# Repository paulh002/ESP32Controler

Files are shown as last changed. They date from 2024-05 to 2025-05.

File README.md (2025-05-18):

# This repo is archived
Current Arduino version has made this project not fitting anymore in the ESP32 also libraries have updated and are not matching with the code any more.
This repo is only for reference.

# ESP32 USB CAT Controler

A USB remote control for sdrberry or other CAT enabled SDR or VFO
It also for sdrberry controles bandpassfilter and lpf

ToDo:
- add i2c for LPF and BPF

Done:
- USB CAT interface support 

Please add/modify a file credentials.h to the source files for wifi
```
#ifndef _CREDENTIALS_H_			// Prevent double inclusion
#define _CREDENTIALS_H_

#define NUMBR_SSID  2
const char* _ssid[] = {"wifi-ssid1", "wifi-ssid2" };
const char* _password[] = {"password", "password"};

#endif
```

sdrberry

Radioberry demo (https://youtu.be/PQ_Np5SfcxA)

# ESP32 Remote control for raspberry pi
sdrberry

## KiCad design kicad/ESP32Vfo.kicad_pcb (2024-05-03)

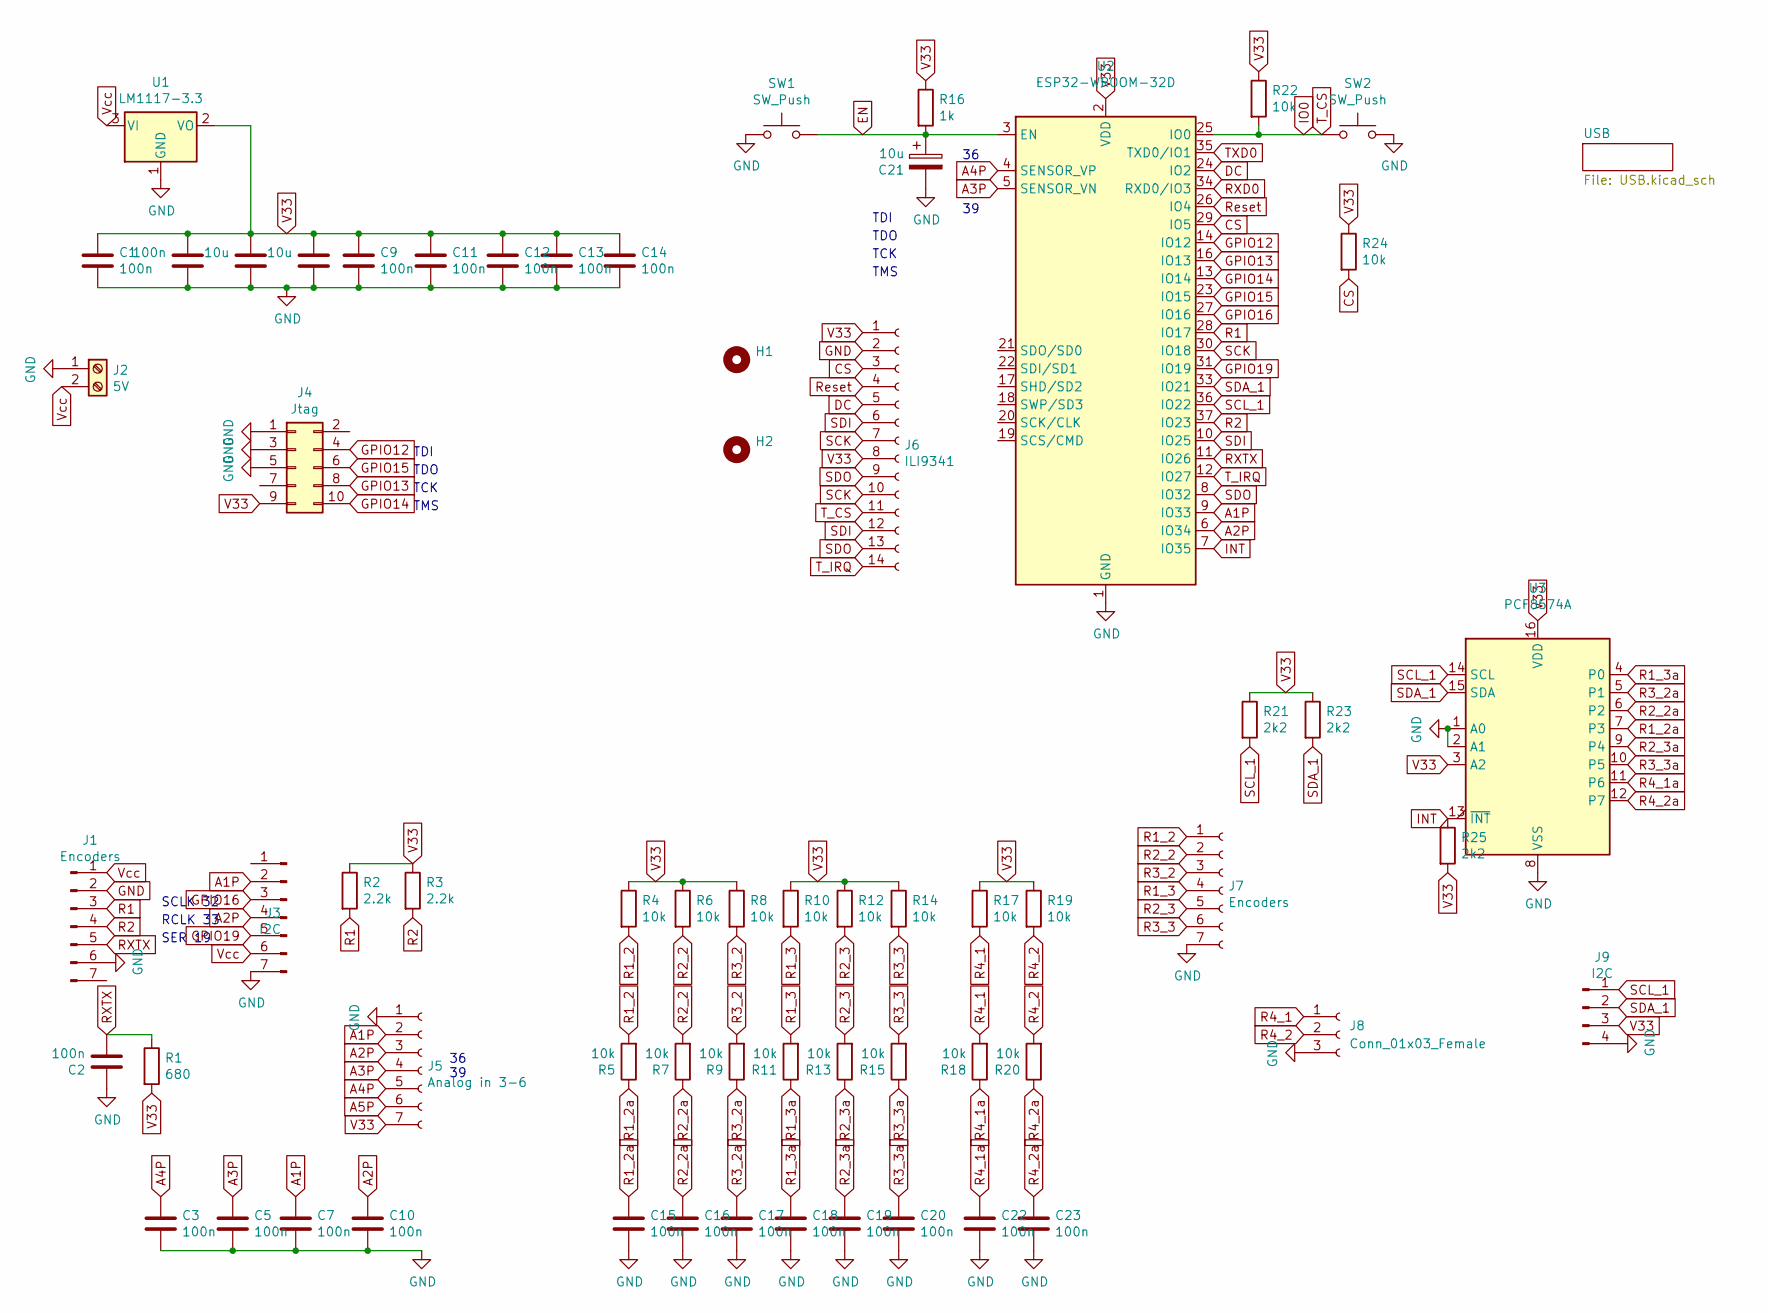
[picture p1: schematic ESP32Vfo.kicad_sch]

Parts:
C1, C2, C3, C4, C5, C7, C9, C10, C11, C12, C13, C14, C15, C16, C17, C18, C19, C20, C22, C23: 100n; C_0805_2012Metric
C6, C21: 10u; C_1206_3216Metric_Pad1.42x1.75mm_HandSolder
C8: 10u; C_0805_2012Metric
H1, H2: MountingHole_3.2mm_M3
J1, J7: Encoders; PinSocket_1x07_P2.54mm_Vertical
J2: 5V; TerminalBlock_MetzConnect_Type011_RT05502HBWC_1x02_P5.00mm_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
J3: I2C; PinSocket_1x07_P2.54mm_Vertical
J4: Jtag; PinSocket_2x05_P2.54mm_Vertical
J5: Analog in 3-6; PinSocket_1x07_P2.54mm_Vertical
J6: ILI9341; PinSocket_1x14_P2.54mm_Vertical
J8: Conn_01x03_Female; PinSocket_1x03_P2.54mm_Vertical
J9: I2C; JST_PH_S4B-PH-SM4-TB_1x04-1MP_P2.00mm_Horizontal
R1: 680; R_0805_2012Metric
R2, R3: 2.2k; R_0805_2012Metric
R4, R5, R6, R7, R8, R9, R10, R11, R12, R13, R14, R15, R17, R18, R19, R20, R22, R24: 10k; R_0805_2012Metric
R16: 1k; R_0805_2012Metric
R21, R23, R25: 2k2; R_0805_2012Metric
SW1, SW2: SW_Push; TS-1088R-02526
U1: LM1117-3.3; SOT-223-3_TabPin2
U2: ESP32-WROOM-32D; ESP32-WROOM-32
U3: PCF8574A; SOP-16_7.5x10.4mm_P1.27mm

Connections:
A1P: C7.2, J3.2, J5.2, U2.9 (IO33)
A2P: C10.2, J3.4, J5.3, U2.6 (IO34)
A3P: C5.2, J5.4, U2.5 (SENSOR_VN)
A4P: C3.2, J5.5, U2.4 (SENSOR_VP)
A5P: J5.6
CS: J6.3, R24.2, U2.29 (IO5)
DC: J6.5, U2.24 (IO2)
EN: C21.1, R16.2, SW1.2, U2.3 (EN); also elsewhere on the board
GND: C1.1, C2.2, C3.1, C4.2, C5.1, C6.2, C7.1, C8.2, C9.1, C10.1, C11.1, C12.1, C13.1, C14.1, C15.1, C16.1, C17.1, C18.1, C19.1, C20.1, C21.2, C22.1, C23.1, J1.2, J1.6, J2.1, J3.7, J4.1, J4.3, J4.5, J5.1, J6.2, J7.7, J8.3, J9.4, SW1.1, SW2.2, U1.1 (GND), U2.1 (GND), U2.15 (GND), U2.38 (GND), U2.39 (GND), U3.1 (A0), U3.2 (A1), U3.8 (VSS); also elsewhere on the board
GPIO12: J4.4, U2.14 (IO12)
GPIO13: J4.8, U2.16 (IO13)
GPIO14: J4.10, U2.13 (IO14)
GPIO15: J4.6, U2.23 (IO15)
GPIO16: J3.3, U2.27 (IO16)
GPIO19: J3.5, U2.31 (IO19)
INT: R25.1, U2.7 (IO35), U3.13 (~INT)
IO0: J6.11, R22.2, SW2.1, U2.25 (IO0); also elsewhere on the board
R1: J1.3, R2.2, U2.28 (IO17)
R1_2: J7.1, R4.2, R5.2
R1_2a: C15.2, R5.1, U3.7 (P3)
R1_3: J7.4, R10.2, R11.2
R1_3a: C18.2, R11.1, U3.4 (P0)
R2: J1.4, R3.2, U2.37 (IO23)
R2_2: J7.2, R6.2, R7.2
R2_2a: C16.2, R7.1, U3.6 (P2)
R2_3: J7.5, R12.2, R13.2
R2_3a: C19.2, R13.1, U3.9 (P4)
R3_2: J7.3, R8.2, R9.2
R3_2a: C17.2, R9.1, U3.5 (P1)
R3_3: J7.6, R14.2, R15.2
R3_3a: C20.2, R15.1, U3.10 (P5)
R4_1: J8.1, R17.2, R18.2
R4_1a: C22.2, R18.1, U3.11 (P6)
R4_2: J8.2, R19.2, R20.2
R4_2a: C23.2, R20.1, U3.12 (P7)
RXD0: U2.34 (RXD0/IO3); also elsewhere on the board
RXTX: C2.1, J1.5, R1.1, U2.11 (IO26)
Reset: J6.4, U2.26 (IO4)
SCK: J6.7, J6.10, U2.30 (IO18)
SCL_1: J9.1, R21.2, U2.36 (IO22), U3.14 (SCL)
SDA_1: J9.2, R23.2, U2.33 (IO21), U3.15 (SDA)
SDI: J6.6, J6.12, U2.10 (IO25)
SDO: J6.9, J6.13, U2.8 (IO32)
TXD0: U2.35 (TXD0/IO1); also elsewhere on the board
T_IRQ: J6.14, U2.12 (IO27)
V33: C1.2, C4.1, C6.1, C8.1, C9.2, C11.2, C12.2, C13.2, C14.2, J4.9, J5.7, J6.1, J6.8, J9.3, R1.2, R2.1, R3.1, R4.1, R6.1, R8.1, R10.1, R12.1, R14.1, R16.1, R17.1, R19.1, R21.1, R22.1, R23.1, R24.1, R25.2, U1.2 (VO), U2.2 (VDD), U3.3 (A2), U3.16 (VDD); also elsewhere on the board
Vcc: J1.1, J2.2, J3.6, U1.3 (VI); also elsewhere on the board

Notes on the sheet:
TDI
TMS
TCK
TDO
SER 19
SCLK 32
RCLK 33
36 39

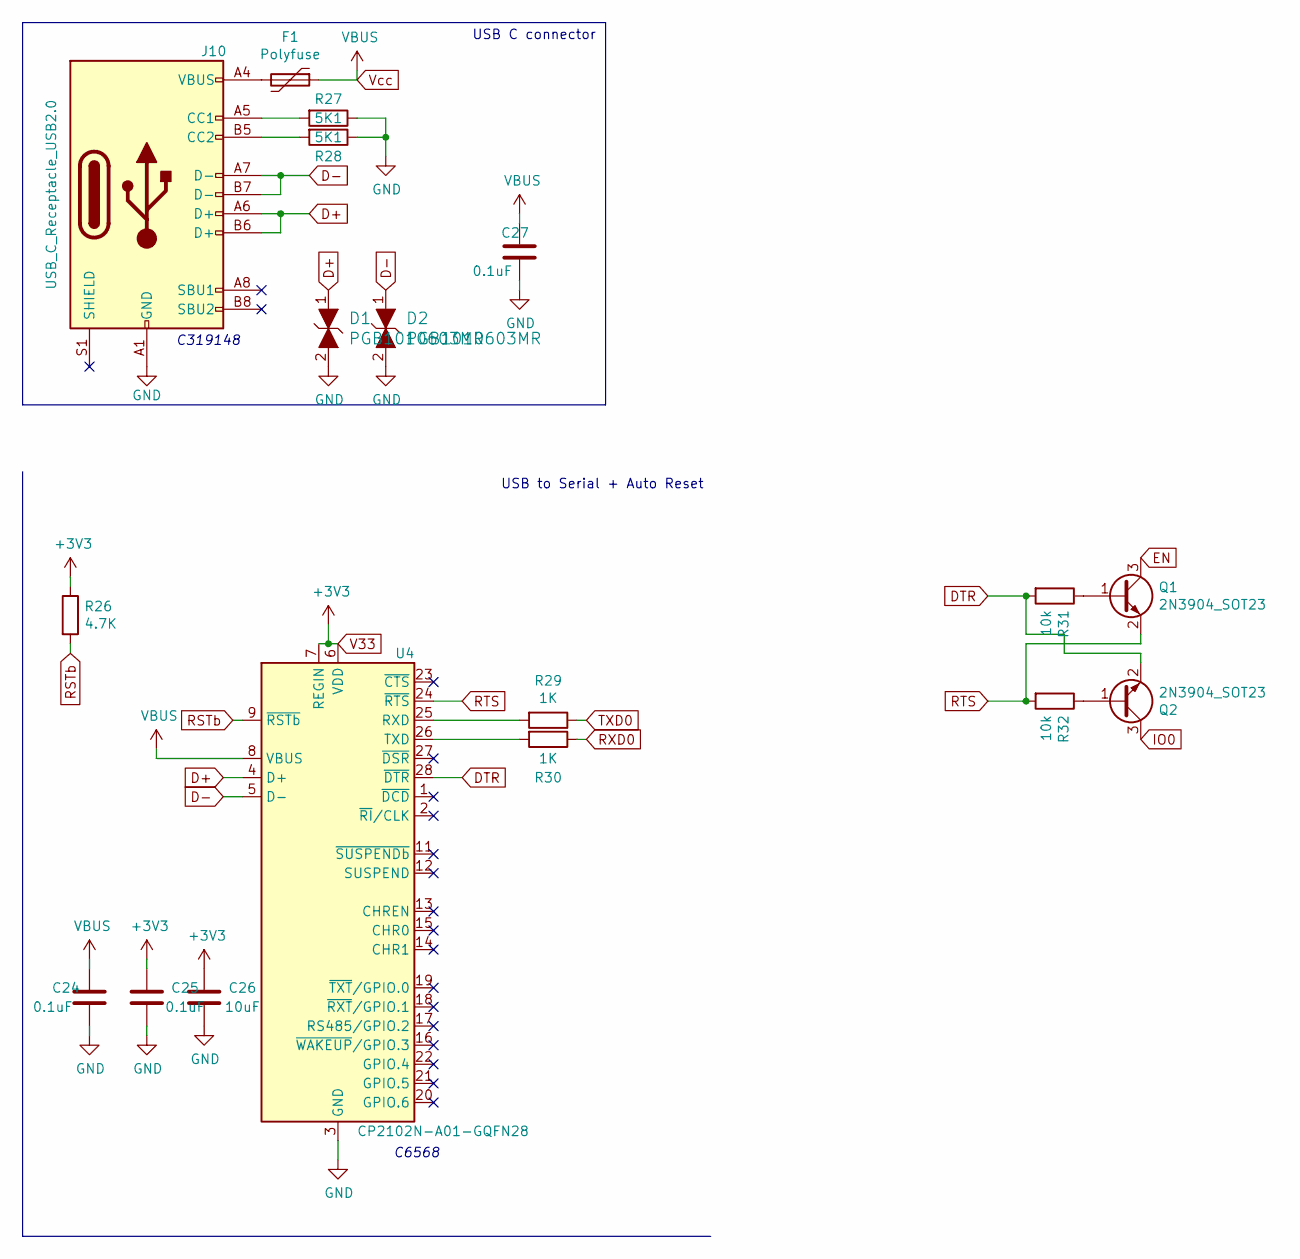
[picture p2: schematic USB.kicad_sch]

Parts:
C24, C25, C27: 0.1uF; C_0805_2012Metric
C26: 10uF; C_0805_2012Metric
D1, D2: PGB1010603MR; 0603; MPN PGB1010603MR; Digi-Key_PN F2594CT-ND
F1: Polyfuse; Fuse_0805_2012Metric
J10: USB_C_Receptacle_USB2.0; USB_C_Receptacle_XKB_U262-16XN-4BVC11
Q1, Q2: 2N3904_SOT23; SOT-23
R26: 4.7K; R_0805_2012Metric
R27, R28: 5K1; R_0805_2012Metric
R29, R30: 1K; R_0805_2012Metric
R31, R32: 10k; R_0805_2012Metric
U4: CP2102N-A01-GQFN28; QFN-28-1EP_5x5mm_P0.5mm_EP3.35x3.35mm

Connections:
D+: D1.1, J10.A6 (D+), J10.B6 (D+), U4.4 (D+)
D-: D2.1, J10.A7 (D-), J10.B7 (D-), U4.5 (D-)
DTR: Q2.2 (E), R31.2, U4.28 (~DTR)
EN: Q1.3 (C); also elsewhere on the board
GND: C24.2, C25.2, C26.2, C27.2, D1.2, D2.2, J10.A1 (GND), J10.A12 (GND), J10.B1 (GND), J10.B12 (GND), R27.1, R28.1, U4.3 (GND), U4.29 (GND); also elsewhere on the board
IO0: Q2.3 (C); also elsewhere on the board
unnamed: F1.2, J10.A4 (VBUS), J10.A9 (VBUS), J10.B4 (VBUS), J10.B9 (VBUS)
unnamed: J10.A5 (CC1), R27.2
unnamed: J10.B5 (CC2), R28.2
unnamed: Q1.1 (B), R31.1
unnamed: Q2.1 (B), R32.1
unnamed: R29.2, U4.25 (RXD)
unnamed: R30.2, U4.26 (TXD)
RSTb: R26.2, U4.9 (~RSTb)
RTS: Q1.2 (E), R32.2, U4.24 (~RTS)
RXD0: R30.1; also elsewhere on the board
TXD0: R29.1; also elsewhere on the board
V33: C25.1, C26.1, R26.1, U4.6 (VDD), U4.7 (REGIN); also elsewhere on the board
Vcc: C24.1, C27.1, F1.1, U4.8 (VBUS); also elsewhere on the board

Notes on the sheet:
USB C connector
USB to Serial + Auto Reset
C319148
C6568

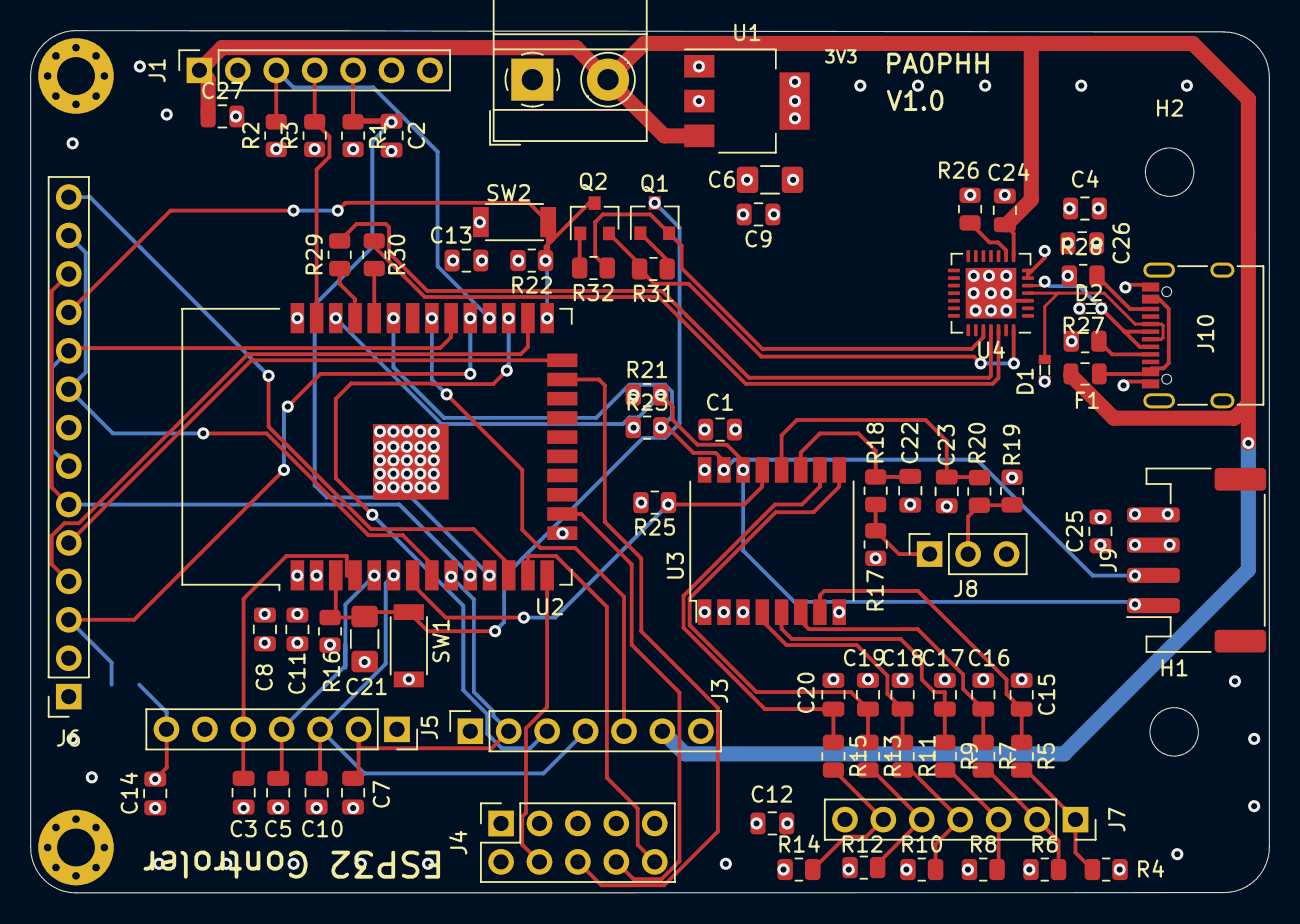
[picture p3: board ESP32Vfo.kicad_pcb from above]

Board: 4 copper layers, 81.9 x 57.0 mm, 84 parts (1 on the bottom side), 58 nets.

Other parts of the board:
H1#2, H2#2: MountingHole_3.2mm_M3

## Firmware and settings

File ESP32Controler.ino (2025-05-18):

/*
 Name:		ESPControler.ino
 Created:	12/1/2022 5:36:30 PM
 Author:	paulh
*/
#include <EEPROM.h>
#include <Wire.h>
#include <WiFi.h>
#include <lvgl.h>
#include "trxnetwork.h"
#include "measurement.h"
#include "credentials.h"
#include "gui.h"
#include "_EEPROMAnything.h"

SemaphoreHandle_t swrBinarySemaphore = NULL;
SemaphoreHandle_t GuiBinarySemaphore = NULL;


// the setup function runs once when you press reset or power the board
void setup() {
	Serial.begin(115200);
	
	//pinMode(S_METER, ANALOG);
	pinMode(FWD_METER, ANALOG);
	pinMode(REV_METER, ANALOG);
	pinMode(TXRX_SWITCH, INPUT);

	GuiBinarySemaphore = xSemaphoreCreateMutex();
	if (GuiBinarySemaphore == NULL) {
		Serial.println("Error creating the GuiBinarySemaphore");
	}
	swrBinarySemaphore = xSemaphoreCreateMutex();
	if (swrBinarySemaphore == NULL) {
		Serial.println("Error creating the swrBinarySemaphore");
	}
	net_queue = xQueueCreate(1, sizeof(uint8_t));
	if (net_queue == NULL) {
		Serial.println("Error creating the queue");
	}
	
	LoadEEPROM();
	start_measurement();
	init_gui();
	delay(10);

	R.wifi_onoff = true;
	if (strlen(R.ssid[0]) == 0) // If no ssid configured take from credentials.h
	{
		for (int i = 0; i < NUMBR_SSID; i++)
		{
			strcpy(R.ssid[i], _ssid[i]);
			strcpy(R.password[i], _password[i]);
		}
	}
	if (R.wifi_onoff)
	{
		for (int i = 0; i < NUMBR_SSID; i++)
		{
			if (strlen(R.ssid[i]))
			{
				Serial.println("Start Wifi");
				if (vfo_network.begin(TRXNET_SERVER))
				{
					return;
				}
			}
		}
	}
}

// the loop function runs over and over again until power down or reset


void loop() {

		if (net_queue)
		{ // Check if we need to start or stop wifi
			uint8_t message;
			if (xQueueReceive(net_queue, &message, 0))
			{
				if (message == 0)
				{
					// stopwifi
					vfo_network.network_stop();
				}
				if (message == 1)
				{
					// startwifi
					vfo_network.begin(TRXNET_SERVER);
				}
			}
		}
		vfo_network.network_loop();
		delay(1);
}


void LoadEEPROM()
{
	uint8_t coldstart;

	EEPROM.begin(sizeof(var_t) + sizeof(uint8_t));

	coldstart = EEPROM.read(0);               // Grab the coldstart byte indicator in EEPROM for
	// comparison with the COLDSTART_REFERENCE

	Serial.println(String("Coldstart : ") + String(coldstart));

	// Initialize all memories if first upload or if COLDSTART_REF has been modified
	// either through PSWR_A.h or through Menu functions

	if (coldstart == COLDSTART_REF-1)
	{
		init_measurement(true);  // upgrade

		EEPROM_readAnything(1, R);               // Read the stored data
		return;
	}

	if (coldstart != COLDSTART_REF)
	{
		init_measurement(false);
		EEPROM.write(0, COLDSTART_REF);          // COLDSTART_REF in first byte indicates all initialized
		EEPROM_writeAnything(1, R);              // Write default settings into EEPROM
		EEPROM.commit();
	}
	else                                      // EEPROM contains stored data, retrieve the data
	{
		EEPROM_readAnything(1, R);               // Read the stored data
	}
}

void SaveEEPROM()
{
	EEPROM.write(0, COLDSTART_REF);          // COLDSTART_REF in first byte indicates all initialized
	EEPROM_writeAnything(1, R);              // Write default settings into  
	EEPROM.commit();
}

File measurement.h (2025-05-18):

#ifndef _MEASUREMENT_H_
#define _MEASUREMENT_H_
#include <string>
/*-------------------------------------------------------
   Optical Rotary encoder settings (used for frequency)
--------------------------------------------------------*/
#define PULSE_INPUT_PIN 23  // Rotaty Encoder A
#define PULSE_CTRL_PIN  17  // Rotaty Encoder B
#define TXRX_SWITCH   26

//#define TXRX_SWITCH   4
//#define S_METER       32            // GPIO port S-Meter
#define FWD_METER     33            // GPIO port Fwd-Meter
#define REV_METER     39             // GPIO port Rev-Meter
#define NUMBR_SSID    5                // Store max 5 ssid's and passwords

#define COLDSTART_REF   99

#define TWENTYTOONE               0 // 1 to select the values for 20 to 1 coupler, else 0
#define SAMPLE_TIMER           1000 // Interrupt timer, in microseconds
#define BUF_SHORT               100 // Buffer size for 100ms Peak
#define PEP_BUFFER               50 // PEP Buffer size in multiples of BUF_SHORT, can hold up to 5 second PEP
#define LONG_BUFFER              30 // LONG Buffer size in multiples of shortest PEP period (1s) - typically 30 seconds
#define AVG_BUF1S              1000 // AVG Buffer sample size (1000 is 1 second, if SAMPLE_TIMER = 1000)
#define AVG_BUFSHORT            100 // Short (100ms) AVG Buffer size
#define AVG_BUFSWR               10 // Very short buffer for SWR bargraph smoothing.  Time is POLL_TIMER*AVG_BUFSWR
#define MODSCOPE_DIVISOR          1 // Modultion Scope scan rate divisor
#define AD8307_INSTALLED		  1
#define CAL1_NOR_VALUE          440 // 40 dBm, default dBm level1 for both AD8307
#define CAL2_NOR_VALUE          217 // 10 dBm, default dBm level2 for both AD8307
#define CALFWD1_DEFAULT       2.04//2.233 // Default raw Voltage level1 at  40 dBm
#define CALREV1_DEFAULT       2.04//2.233 // Default raw Voltage level1 at  40 dBm
#define CALFWD2_DEFAULT       1.7 //1.528 // Default raw Voltage level2 at  10 dBm
#define CALREV2_DEFAULT       1.7 //1.528 // Default raw Voltage level2 at  10 dBm
#define PEP_PERIOD (2500000/SAMPLE_TIMER)/BUF_SHORT // 2.5 seconds = Default
#define CAL_BAD  0                                      // Input signal of insufficient quality for calibration
#define CAL_FWD 1                                      // Good input signal detected, forward direction
#define CAL_REV 2                                      // Good input signal detected, reverse direction (redundant)
#define CAL_SCALE_WATT          50  // default scale for watt output meter
#define SI5351_XTAL_FREQ 2500000000
#if TWENTYTOONE                     // Defs when using a 20 to 1 coupler and AD7991
#define MIN_PWR_FOR_SWR_CALC   0.5  // Minimum Power in mW for SWR calculation and display
#else                               // Defs when using a 30 to 1 coupler and AD7991
#define MIN_PWR_FOR_SWR_CALC   1.0  // Minimum Power in mW for SWR calculation and display
#endif
#define MIN_PWR_FOR_SWR_SHOW  0.01  // Minimum Power in mW for SWR indication (use recent value)

//-----------------------------------------------------------------------------
// Timer for Power/SWR calculations and LCD prints, milliseconds
#define POLL_TIMER               10 // Meter updates will be at half this rate
                                    // Text updates will be at quarter of this rate
                                    // 
//-----------------------------------------------------------------------------
// DEFS for FWD and REF coupler, 2xAD8307 or Diode detectors
//-----------------------------------------------------------------------------
// DEFS for AD8307 Calibration (dBm *10)
// levels for the forward and reverse measurements - in order to allow a Calibration
//
// Note that the AD8307 generates 2uA per dB and applies an internal resistor of 12.5kohms
// 2uA * 12.5kohm gives the specified slope of 25mV/dB.  
// Unloaded Teensy 3.2 AD inputs appear to have an impedance of approx 200 kohms,
// hence the voltage slope is slightly affected:
// 12.5k||200k = 11.75k.  2uA * 11.75k gives a slope value of 23.5mV/dB.
// However if the meter has a voltage divider made out of RS=15kohm and RP=10kohm, 
// then the slope would need to be recalculated like below:
// 12.5k||25k = 8.333k.  2uA * 8.333k then gives a slope value of 16.67mV/dB 
// or if RS = 47kohm and RP = 33kohm (RS+RP = 80 kohm), then:
// 12.5k||80k = 10.81k.  2uA * 10.81k gives a slope value of 21.62mV/dB
//
#define LOGAMP1_SLOPE          23.5 // mV/dB.  Used with Single Level Calibration
#define LOGAMP2_SLOPE          23.5 // mV/dB.  Used with Single Level Calibration
                                    // Typical value for AD8307 is 25mV/dB if AD input is ~1Mohm or higher
                                    // Typical value for ADL5519 is 22mV/dB
//-----------------------------------------------------------------------------
#define CAL_INP_QUALITY        12.0 // (dB) Minimum difference between the Fwd and Rev
                                    // signals to be allowed to calibrate
//-----------------------------------------------------------------------------

//-----------------------------------------------------------------------------
// ADC Reference Voltage and Voltage Drop Definitions
#define ADCREF_BUILTIN            0 // 1 for builtin 1.2V reference, 0 for external 3.3V reference
//-----------------------------------------------------------------------------
// Automatic, no need to do anything with these (unless external voltage regulator is not exactly 3.3V)
#if ADCREF_BUILTIN
#define ADC_REF                1.20 // Internal Reference voltage for ADC
#else
#define ADC_REF                3.30 // External Reference voltage for ADC
#endif
//-----------------------------------------------------------------------------
// Resistors for Voltage Drop before AD input - used when internal 1.2V reference
// and/or when Diode Detector type coupler is used instead of a 2x AD8307 coupler.
#define RS                      0.0 // Series Resistor between measured voltage and ADC_IN (k ohm)
#define RP                     10.0 // Parallel Resistor, ADC_IN to ground for ADC_IN voltage drop (k ohm)
                                    // If no RS and RP, then set RS as 0 and RP as any non-zero value                                   
//-----------------------------------------------------------------------------
 // Equivalent Reference Voltage, derived from ADC_REF & voltage drop resistors
#define ADC_RES  ADC_REF*(RS+RP)/RP // Don't touch, automaticcally derived from the above


#ifndef SQR
#define SQR(x) ((x)*(x))
#endif
#ifndef ABS
#define ABS(x) ((x>0)?(x):(-x))
#endif

//-----------------------------------------------------------------------------
// Structures and Unions
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

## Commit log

2022-10-26 pcf8574 encoders
2023-03-05 add tx switch
2023-03-05 update TX switching
2024-05-03 add kicad files
    [ESP32Vfo.kicad_pcb, ESP32Vfo.kicad_sch, USB.kicad_sch]
